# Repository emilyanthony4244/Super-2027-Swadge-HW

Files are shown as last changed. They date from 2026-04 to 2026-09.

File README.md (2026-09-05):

# Super Magfest 2027 Swadge Hardware

## Welcome

This is the hardware repository for the Super Magfest 2027 Swadge.

The corresponding firmware repository for the Super Magfest 2027 Swadge [can be found here](https://github.com/AEFeinstein/Super-2024-Swadge-FW).

If you have any questions, feel free to create a Github ticket or email us at circuitboards@magfest.org.

## Render

Coming eventually!

## Schematic

Coming eventually!

## Directories

### `art`

This directory has the SVGs used to generate the KiCad files. The SVGs are drawn in [Inkscape](https://inkscape.org/).

### `docs`

This directory has documentation on the hardware. [Start Here](/docs/structure.md)  

### `Swadge-Parts`

This directory is a git submodule which has all the parts, footprints, and 3D models used in the KiCad project.

### `Swadge-HW`

This directory has the KiCad project for the main Swadge PCB.

### `Swadge-HW/3d Print`

This directory has the 3D print files for the 2027 Swadge.

### `Swadge-HW/Manufacturing Information`

This directory has information about manufacturing the Swdage PCB.

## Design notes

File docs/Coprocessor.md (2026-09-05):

# CH32 Coprocessor
The Swadge has a CH32V003F4U6 as a coprocessor

## Pin Assignment

| PIN | FUNCTION | NOTE |
| --- | --- | --- |
| 1 | BTN_1 | Can be made reset pin |
| 2 | TOUCH_A | --- |
| 3 | TOUCH_G | --- |
| 4 | GND | --- |
| 5 | BTN_5 "Right" | --- |
| 6 | 3V3 | --- |
| 7 | BTN_2 "Left" | --- |
| 8 | Unused | --- |
| 9 | BTN_4 "Down" | --- |
| 10 | Unused | --- |
| 11 | VMON | ADC |
| 12 | CHARGE | --- |
| 13 | STANDBY | --- |
| 14 | BTN_6 "MENU" | --- |
| 15 | CH32_COMMS | --- |
| 16 | BTN_3 "PAUSE" | --- |
| 17 | BTN_8 "B" | --- |
| 18 | BTN_7 "A" | --- |
| 19 | TOUCH_21 | --- |
| 20 | TOUCH_M | --- |

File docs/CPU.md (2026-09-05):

# Background
The Swadge is powered by an ESP32 module with integrated bluetooth antenna

# Pin Assignment ESP32-S3-WROOM-1-N16R8

## Fixed Assignment

The following IO is fixed by hardware constraints and cannot be reassigned

1 - Ground  
2 - 3V3 
3 - Chip Enable 
13 - USB(-)  
14 - USB(+)  
27 - Boot Pin
28 - Not Connected, Reserved for PSRAM  
29 - Not Connected, Reserved for PSRAM 
30 - Not Connected, Reserved for PSRAM 
37 - TXD0  
36 - RXD0  

## Pin Table

| Pin Number | IO | Use | Alternate Features | Notes |
| --- | --- | --- | --- | --- |
| 1 | Ground | Ground | N/A | --- |
| 2 | 3V3 | 3V3 | N/A | --- |
| 3 | EN | EN | N/A | --- |
| 4 | GPIO4 | TOUCH4 | ADC1_CH3 | --- |
| 5 | GPIO5 | TOUCH5 | ADC1_CH4 | --- |
| 6 | GPIO6 | TOUCH6 | ADC1_CH5 | --- |
| 7 | GPIO7 | TOUCH7 | ADC1_CH6 | --- |
| 8 | GPIO15 | SAO_A | XTAL_32K_P, ADC2_CH4 | --- |
| 9 | GPIO16 | SAO_B | XTAL_32K_N, ADC2_CH5 | --- |
| 10 | GPIO17 | MIC via ADC2_CH6 | ADC2_CH6 | --- |
| 11 | GPIO18 | TFT_RESET | ADC2_CH7 | --- |
| 12 | GPIO8 | TOUCH8 | ADC1_CH7| --- |
| 13 | GPIO19 | USB (-) | GPIO19, ADC2_CH8 | --- |
| 14 | GPIO20 | USB (+) | GPIO20, ADC2_CH9 | --- |
| 15 | GPIO3 | TOUCH3 | ADC1_CH2 | --- |
| 16 | GPIO46 | Unused  | --- | Strapping Pin |
| 17 | GPIO9 | TOUCH9 | GPIO9, ADC1_CH8 | --- |
| 18 | GPIO10 | FSPI_CS0 (LCD) | GPIO10, TOUCH10, & ADC1_CH9 | --- |
| 19 | GPIO11 | FSPID - TFT_SDA | GPIO11, TOUCH11, & ADC2_CH0 | --- |
| 20 | GPIO12 | FSPICLK - TFT_CLK | GPIO12, TOUCH12, ADC2_CH1 | --- |
| 21 | GPIO13 | TFTATP | GPIO13, TOUCH13, ADC2_CH2 | --- |
| 22 | GPIO14 | TOUCH14 | GPIO14, ADC2_CH3 | --- |
| 23 | GPIO21 | SLEEP | GPIO21 | --- |
| 24 | GPIO47 | SPK | GPIO47 | --- |
| 25 | GPIO48 | SPK_SHDN | GPIO48 | --- |
| 26 | GPIO45 | Unused | GPIO45 | N/A | Strapping Pin |
| 27 | GPIO0 | Boot / "Button UP"| GPIO0 | Strapping Pin for Boot Source |
| 28 | GPIO35 | Not Connected | GPIO35 | Reserved for Octal SPI PSRAM |
| 29 | GPIO36 | Not Connected | GPIO36 | Reserved for Octal SPI PSRAM |
| 30 | GPIO37 | Not Connected | GPIO37 | Reserved for Octal SPI PSRAM |
| 31 | GPIO38 | TFT_RS | GPIO38 | --- |
| 32 | GPIO39 | CH32_COMMS | GPIO39 | --- |
| 33 | GPIO40 | I2C_SDA  | GPIO40 | --- |
| 34 | GPIO41 | I2C_SCL  | GPIO41 | --- |
| 35 | GPIO42 | LED | GPIO42 | --- |
| 36 | RXD0 | RXD0 | GPIO44 | --- |
| 37 | TXD0 | TXD0 | GPIO43 | --- |
| 38 | GPIO2 | TOUCH2 | GPIO2 & ADC1_CH1 | --- |
| 39 | GPIO1 | TOUCH1 | GPIO1 & ADC1, CH2 | --- |
| 40 | GND | GND | --- | --- |
| 41 | GND | GND | --- | --- |

# Basic Operation

## BOOT
When the ESP32 Module first receives power, it enters its Chip Reset State. The Chip Reset State can also be induced by using a physical tool to short EN (PIN 3) to ground. The recommended way of doing this is by shorting C13 with a screwdriver if removal of the battery is not desired.

In the Reset State the status of the four strapping pins combined with the e-fuses determine the boot configuration.

Chip Boot Mode is determined by GPIO0 and GPIO46.
GPIO0 has a default weak internal pull up as well as a 10k external pull up via R12. GPIO0 can be pulled low by holding the "UP" button during the boot initialization. 
GPIO46 has a default weak internal pull down, and is otherwise unused on the Swadge. It should always be held low on Reset.

When GPIO0 is High, its default state, the ESP32 boots from its SPI flash memory.
When GPIO0 is Low, it enters download boot mode. In this mode the ESP32 will boot via USB, Serial, or JTAG.

## SLEEP
When Pin 23 is pulled low by the power switch the ESP32 is pulled into ULP deep sleep.
The Power Management Unit is operating any time the chip has power.
The ESP32 has four predefined power modes: Active, Modem Sleep, Light Sleep, and Deep Sleep

### Deep-Sleep
When in deep sleep the system is running on its internal RC_SLOW_CLK. Only select RTC ULP peripherals are available.

### Light-Sleep
When in light sleep the high speed clock and CPUs are not running, but the digital system retains the memory state to resume operation.

### Modem-Sleep
When in modem sleep everything is operating except the analog RF radio circuits.

## Watchdogs
There are four watchdog times:
Super Watchdog (SWD), RTC Watchdog (RWDT), and Two Main System Watchdogs (MWDT0 & MWDT1)

### Analog Super Watchdog
The SWD is a base analog timer that must be reset every second by the ULP coprocessor or the ESP32 will enter the [Reset State](#boot). The SWD has an interrupt register that will indicate a request aproximately 100ms before the SWD expires.

### Digital Watchdog
RWDT, MWDT0, and MWDT1 are 32 bit counters which have four programable trigger points. Each trigger point can select from the following actions: Disabled, Interrupt, CPU Reset (Of a single processor), and Core reset. RWDT additionally has access to the action of [System Reset](#boot). By default, stage 0 for RWDT is set to system reset during the initial boot process, to allow for automatic recovery.

# Ultra Low Power Coprocessor

# RISC Processor Cores

# PERIPHERALS

## UART

## I2C

## SPI

## LED PWM

## Touch Sensing

## ADC

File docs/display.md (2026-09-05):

# TFT Display

The Swadge has a RB017A1505A Display

Backlight is controlled via PWM though signal TFTATP

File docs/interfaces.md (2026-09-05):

# Swadge Interfaces

The Swadge has the following interfaces:
USB 2.0 via J1, between the [CPU](/docs/CPU.md) and the USB port  
UART programming
SAO port, including two GPIO and I2C  
Audio Aux Port  

## USB

The USB 2.0 signal from the port to the CPU
Have an approximately 90 ohm differential impedance. It is recommended to achieve this with a tightly coupled routing and coplanar ground.
> Recommended 9.5 mil trace width with 5 mil spacing when coplanar ground is used.
The USB port to ESP32 trace length should be less than 2 inches
trace length must be less than 6 inches.
The USB lines should have termination resistors at the USB Jack.
The USB lines should have a total skew offset of less than 50ps

## I2C

The I2C_SDA and I2C_SCL lines should be routed with a total skew offset between them of no more than 200ps
It is recommended to have termination resistors at the furthest end of the I2C lines from the ESP32
It is recommended to run I2C lines through pads rather than stub them off to minimize all stub lengths. The SAO will by necessity be the longest stub.

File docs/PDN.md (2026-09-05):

# Background
The Power Distribution Network is the subsystem responsible for generating all applicable global voltage rails from the available power sources.
The global power rails are “GND” and “3V3”
The available power sources are “5VIN” and “V_BATT”
Local power rails are “2V8_LCD”, “TFT_LED”

| Net | Description | Interface |
| --- | --- | --- |
| GND | Global Ground Net, common return path for all portions of the swadge with the exception of the isolated BATT_N | Global |
| 3V3 | Global 3.3V DC power supply | Global |
| 5VIN | USB Supplied 5V DC, Used to either power the swadge or to recharge the onboard battery | J1 |
| BATT_P | Battery Positive Voltage | --- |
| BATT_N | Battery Negative Voltage, U4 Isolates the battery return from global ground when 
| LCD28 | 2.8V Display Logic Power | --- |
| TFT_LEDA | PWM Display Backlight Power | --- |

# Requirements
The PDN shall accept a nominal 5V DC from USB input J1
The PDN shall provide power from the USB source when 5VIN is in the range of 4.35VDC to 5.5VDC.
The PDN shall accept a range of voltage from the battery(s) between 2.4V and 5.5V.
The PDN shall generate a regulated 3.3V DC from a range of input voltages for both battery and USB operation
The PDN should minimize both conducted and radiated EMI and its effects on other subsystems of a Swadge and external items.

# Implementation
## Auctioneering
The [3.3V Regulator] (#3V3) is fed from an auctioneered supply via Q2. Q2 and D22 passively switch the source to the system to whichever has the higher voltage. The total system current passes through fuse F1.

## 3V3  
The 3.3Vdc power is regulated by an aerosemi MT3410 synchronous switching regulator. The MT3410 is a SOT23-5 Package integrated switch and controller. The Feedback reference is 0.6V. The regulator is rated to operate from 2.3 up to 6V input voltage. The control has a 1.9V undervoltage lockout. As Vin drops to the regulator setpoint the control shifts from switching buck to LDO mode. The switching frequency is nominally 1.2MHz.  
A 2.2uF switching inductor is used. The FB network is set up with a 10k and a 43k, for a 10/53 reduction on the Vout to produce a nominal 3.18V output before accounting for component error. The component datasheet recommends a 10uF ceramic capacitor on both the input and output. In the Swadge Prototype a 1uF input capacitor was used and a 1uF paired with a 22uF output capacitor was used.

## Charging
USB Power is provided to the charging circuit in parallel to the system. A TP4056 BMS regulates VBATT to maintain a correct charge profile. an NTC thermistor is used to provide temperature feedback and limit charging in abnormal temperature conditions. The Charging circuit provides two status LEDs for Charging and Standby, as well as digital inputs to the CH32 coproessor. When the USB port is not providing power, the charging system is not active.

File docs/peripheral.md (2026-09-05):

# Summary

The Swadge has many peripherals to enhance user exierpience

## Lighting

The Swadge lighting is performed with SK6812 side firing individually addressable RGB LEDs.  
Each LED acts as a serial shift register with 24bits of RGB data. They are daisy chained together.

## Inertial Measurement Unit

The Swadge has an IMU to detect motion of the device. The IMU reports its measurements over the I2C bus. The IMU has a fixed I2C address of 0x6A

## SAO

There is an Swadge Add-On connector

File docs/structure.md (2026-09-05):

The hardware layout is composed of the following subsections:  
[Primary CPU](/docs/CPU.md)  
[Power Regulation and Distribution Network](/docs/PDN.md)  
[Coprocessor](/docs/Coprocessor.md)  
[User Inputs](/docs/userIO.md)  
[Graphical Display](/docs/display.md)    
[Audio Input/Output](/docs/audio.md)    
[Peripherals](/docs/peripheral.md)  

The Swadge provides the following external interfaces:
USB-C
Programming UART
SAO
Auxiliary Audio Jack\
Wifi
Bluetooth

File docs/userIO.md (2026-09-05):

# The user IO is as follows:  

## Buttons
8 Buttons

| NET | FUNCTION | NOTE |
| --- | --- | --- |
| BTN_1 | UP | Also the Boot |
| BTN_2 | LEFT | --- |
| BTN_3 | PAUSE | --- |
| BTN_4 | DOWN | --- |
| BTN_5 | RIGHT | --- |
| BTN_6 | MENU | --- |
| BTN_7 | A | --- |
| BTN_8 | B | --- |

## Touch
2 Touch Strips, 5 zones each
4 Touch Button Zones

| NET | FUNCTION | IO |
| --- | --- | --- |
| TOUCH_1 | ZONE L1, Top Left | ESP32 |
| TOUCH_2 | ZONE L2, Left | ESP32 |
| TOUCH_9 | ZONE L3, Middle Left | ESP32 |
| TOUCH_14 | ZONE L4, Left | ESP32 |
| TOUCH_3 | ZONE L5, Bottom Left | ESP32 |
| TOUCH_8 | ZONE R1, Top Right | ESP32 |
| TOUCH_4 | ZONE R2, Right | ESP32 |
| TOUCH_5 | ZONE R3, Middle Right | ESP32 |
| TOUCH_6 | ZONE R4, Right | ESP32 |
| TOUCH_7 | ZONE R5, Bottom Right | ESP32 |
| --- | --- | --- |
| TOUCH_21 | Touch Button | --- |
| TOUCH_M | Trihard Top Button | --- |
| TOUCH_A | Trihard Left Button | --- |
| TOUCH_G | Trihard Right Button | --- |

## Analog
1 volume adjust knob

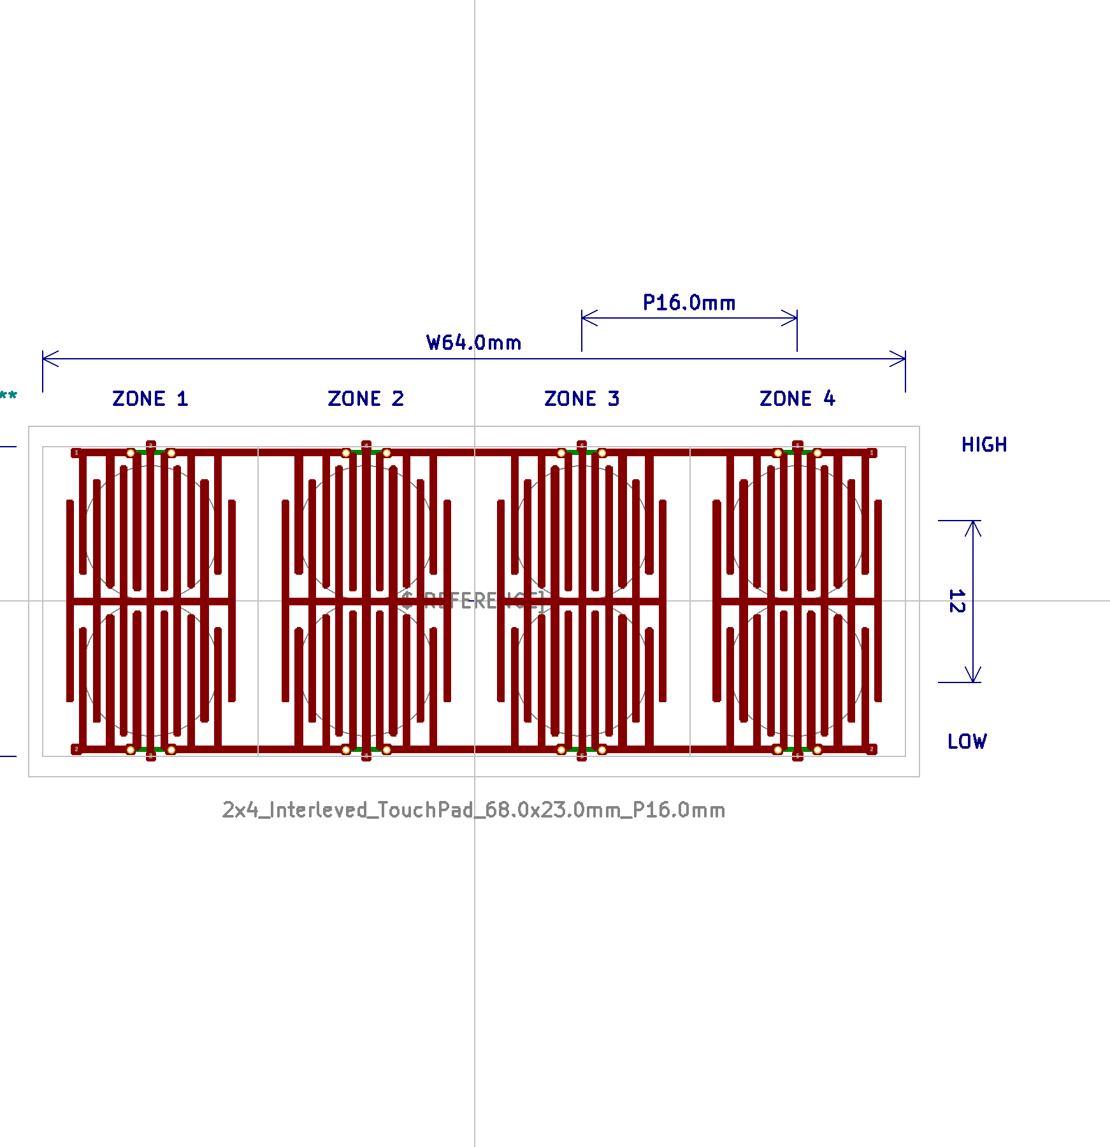
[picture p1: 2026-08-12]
Swadge-HW/.local/2x4_Interleved_TouchPad_68.0x23.0mm_P16.0mm.png

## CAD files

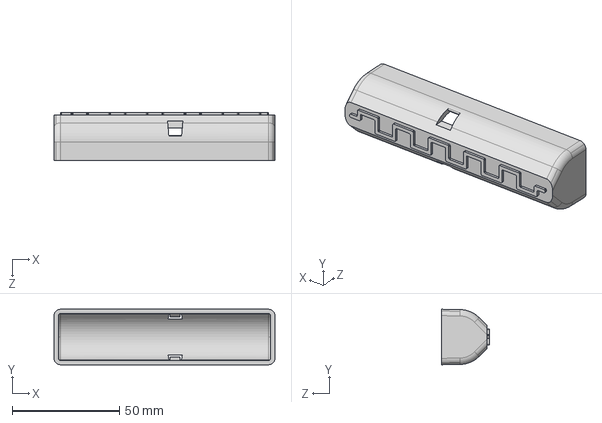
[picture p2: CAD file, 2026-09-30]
3D-Print/Rev1 Battery Cover - IM.STEP
103.1 x 25.9 x 22.2 mm

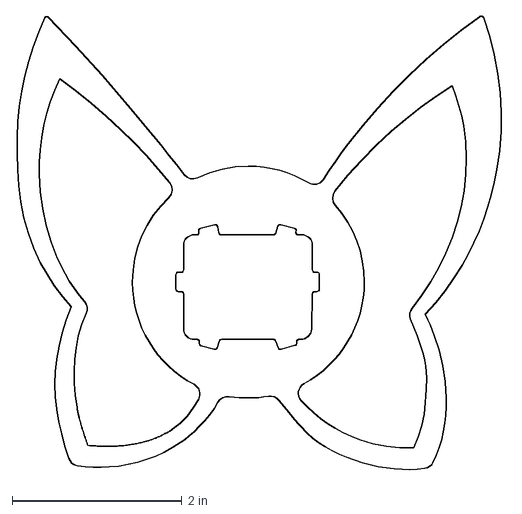
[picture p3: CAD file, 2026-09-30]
art/acylic_9212026.dxf
5.77 x 5.39 in

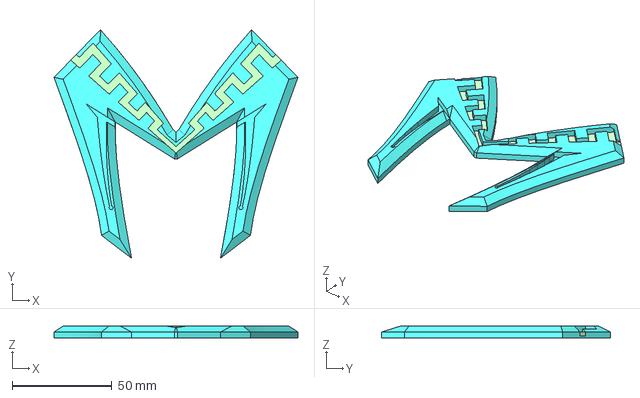
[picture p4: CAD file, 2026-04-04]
Swadge-HW/3D-Print/M-Diffuser.step
122.3 x 114.6 x 6.00 mm

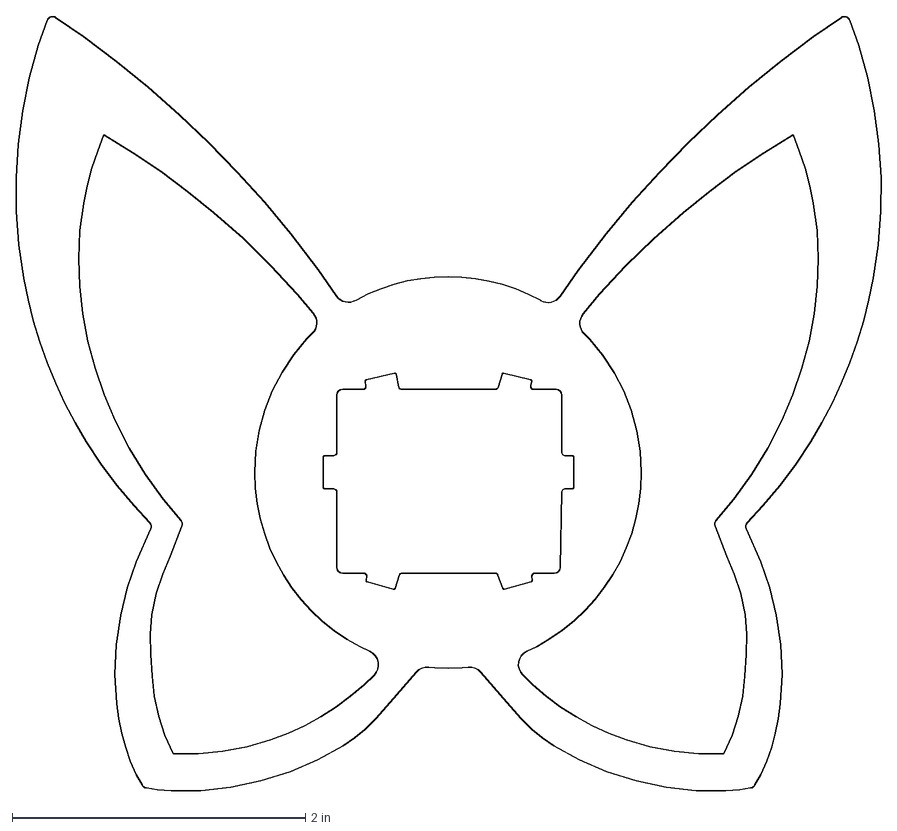
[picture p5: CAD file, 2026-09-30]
art/acylic_9292026.dxf
5.90 x 5.28 in

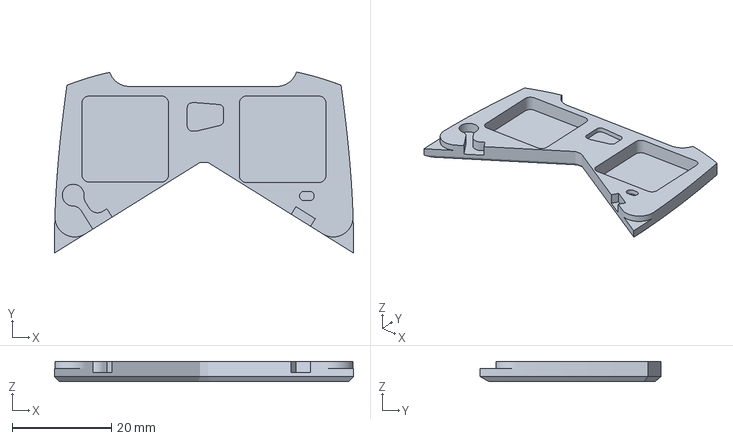
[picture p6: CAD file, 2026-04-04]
Swadge-HW/3D-Print/Open-Visor-orca.3mf
60.3 x 36.5 x 4.05 mm

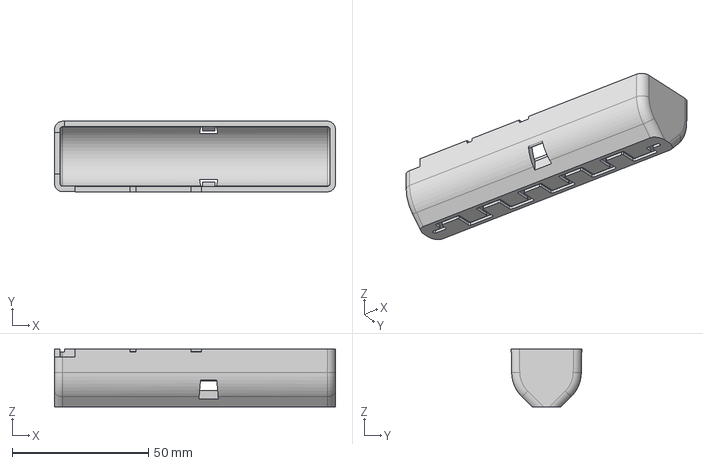
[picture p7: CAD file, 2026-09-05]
3D-Print/Rev0 Battery Cover - 3D Print.step
103.1 x 25.9 x 21.2 mm

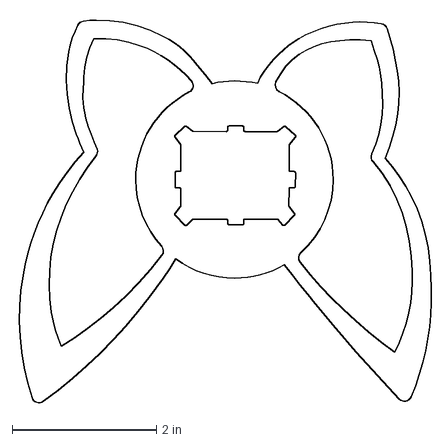
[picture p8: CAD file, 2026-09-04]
art/acrylic.dxf
5.76 x 5.36 in

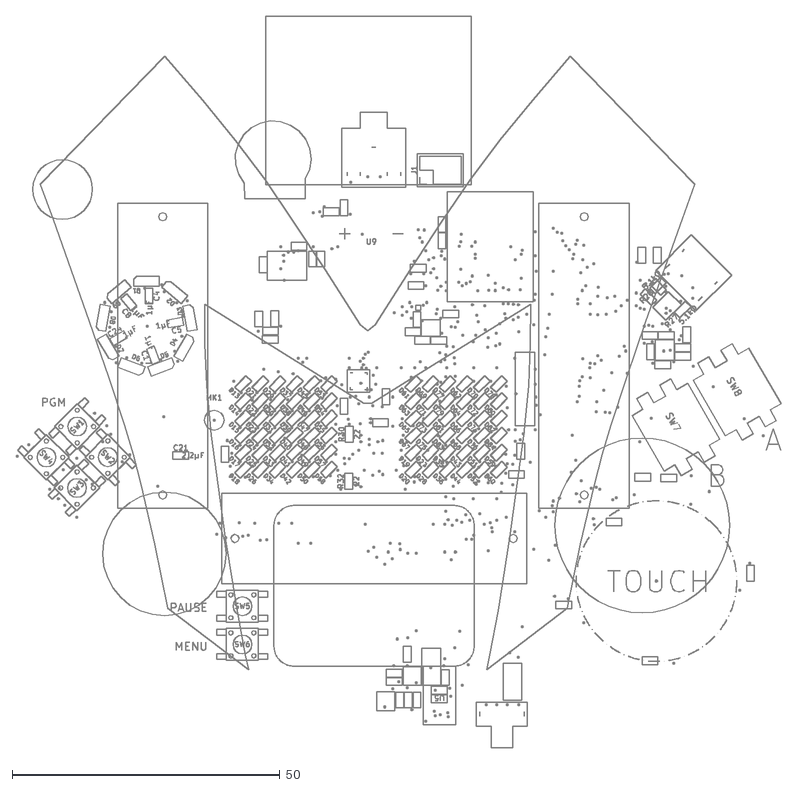
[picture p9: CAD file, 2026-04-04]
art/acrylic_7162025.dxf
142.9 x 136.6

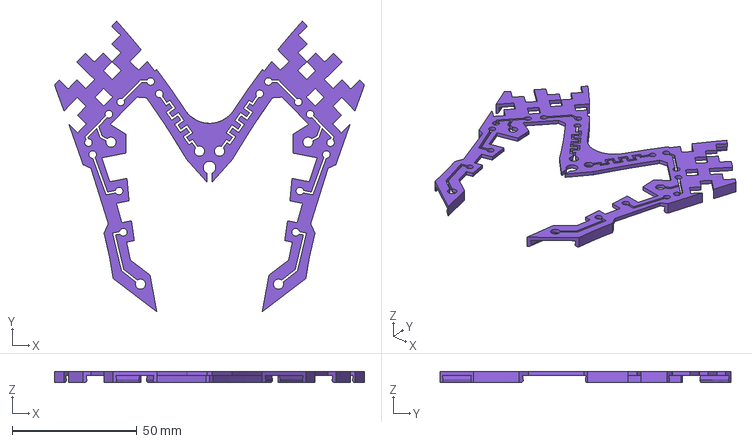
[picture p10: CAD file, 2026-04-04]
Swadge-HW/3D-Print/Corruption Crest.step
124.0 x 116.3 x 4.60 mm

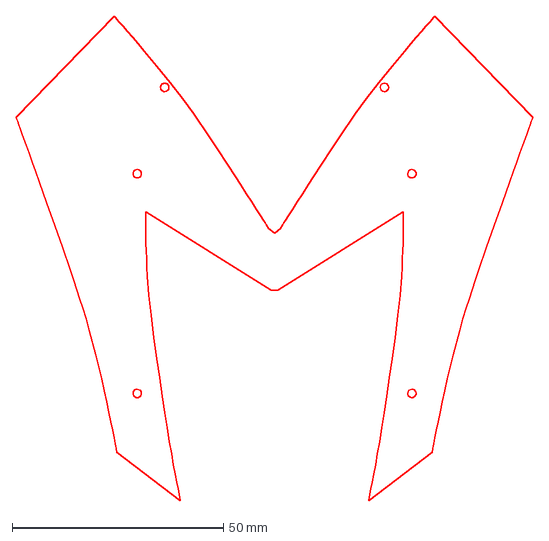
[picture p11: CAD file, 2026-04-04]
art/acrylic_992025.dxf
122.3 x 114.6 mm

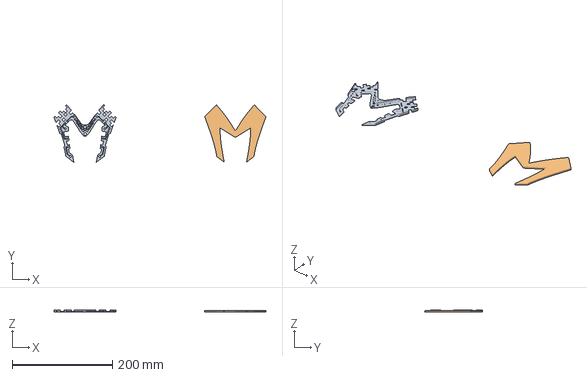
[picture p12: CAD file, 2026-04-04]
Swadge-HW/3D-Print/Corruption-Crest+Acrylic-Orca.3mf
423.2 x 115.4 x 4.60 mm
Corruption-Crest
Faux-Acrylic

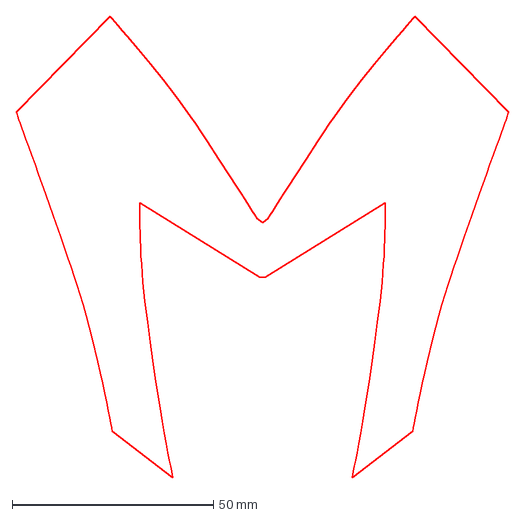
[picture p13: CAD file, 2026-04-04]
art/acylic_10102025.dxf
122.3 x 114.6 mm

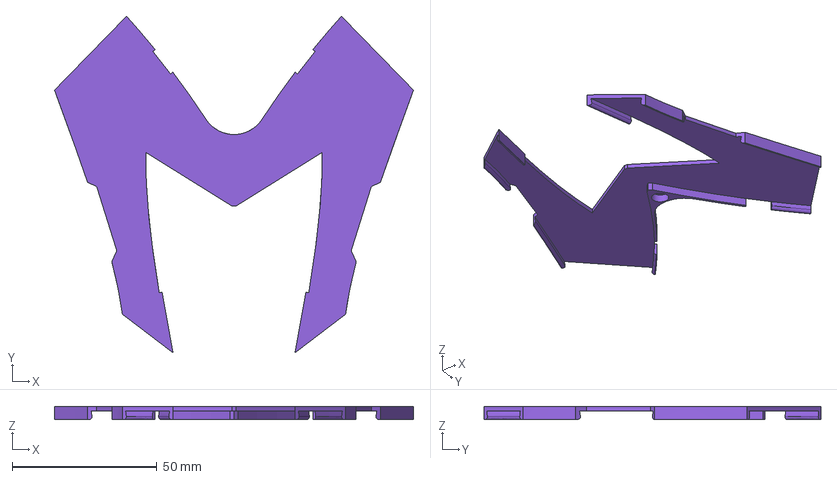
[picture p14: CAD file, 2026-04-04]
Swadge-HW/3D-Print/Crest-Diffuser-Template.step
124.0 x 116.3 x 4.60 mm

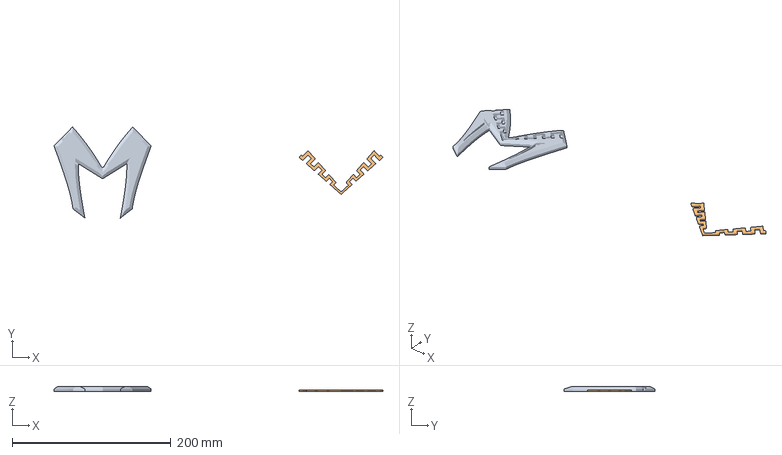
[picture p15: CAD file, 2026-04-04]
Swadge-HW/3D-Print/Fancy-M-Diffuser.3mf
413.9 x 114.6 x 6.00 mm
M-Diffuser.stl_1
M-Diffuser.stl_2

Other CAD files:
Swadge-HW/3D-Print/Pulse-Visor.step
Swadge-HW/3D-Print/Open-Visor-orca-MK4.3mf
Swadge-HW/3D-Print/Wub-Tank-Proto.step
3D-Print/Rev0 Battery Cover - IM.step
3D-Print/Rev0 Battery Cover - IM.SLDPRT

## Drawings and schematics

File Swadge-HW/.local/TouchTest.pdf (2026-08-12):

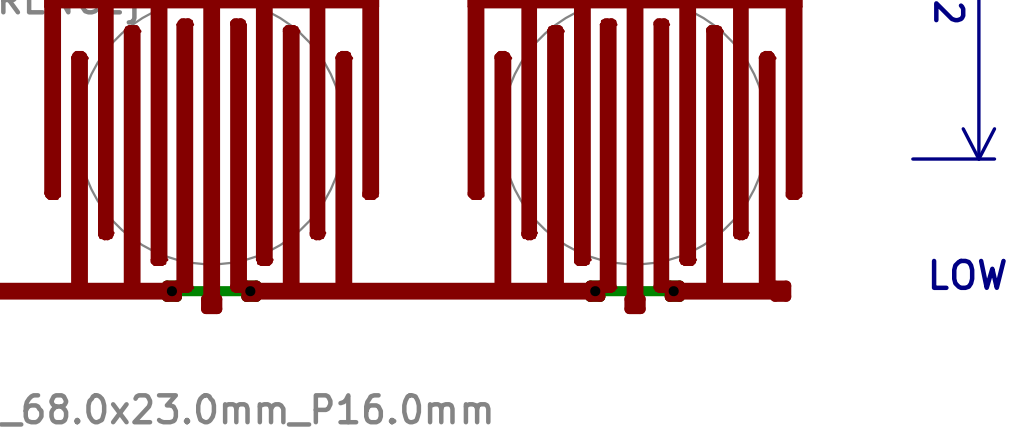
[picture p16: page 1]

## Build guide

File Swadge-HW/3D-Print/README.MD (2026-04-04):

# Super 2026 Swadge 3D Printing Assets

Introducing the WUB TANK, the newest addition to the Swadge shell collection

## Built With

* [Fusion 360]( https://www.autodesk.com/products/fusion-360/overview?term=1-YEAR&tab=subscription) 
* [Blender](https://www.blender.org) 
* [Orcaslicer](https://github.com/OrcaSlicer/OrcaSlicer?tab=readme-ov-file)

## Getting Started

The included files are STEP type so they can be modified to your liking, and most slicer programs will readily load them. The Wub-Tank-Proto.step is the final fit check model before art assets were added. Designed to be readily printable. Recommended settings: 0 top/bottom layers for exposed (honeycomb) infill effect when printed as is.

## Recommended Materials

PLA 
PETG
TPU

## Assembly

The WUB TANK Shell requires a single M3x8 screw.

## Secret 3D Upgrade Add-ons

In addition to the shell model, there are a number of 3D-printable accessories for the Swadge this year. There are STEP files for each, and customized Orcaslicer 3MF project files are also included as reference, or ready to print for the Prusa Core ONE. 

- Pulse-Visor: SPECIFIC FILAMENT REQUIRED. The Pulse Visor was designed to be printed with Cookiecad "Black Star Stuff PLA". Clear PLA or PETG should work as well. As long as the filament isn't to opaque, the lens region of the visor should be thin enough to see the LED's but they may be obscured. Install using thin double-sided tape. Try printing this with a holographic print bed. Enjoy!

- Corruption Crest: A friction fit add-on that attaches to the standard acrylic diffuser. It was designed to be one of several Megaman style powerups. I recommend printing this in purple filament.

- Crest Diffuser Template: A version of the corruption crest with all original art removed so you can design your own. GO NUTS! Just don't cut away the tabs that hold it on.

- M-Diffuser: WARNING ADVANCED!!! Designed as a substitute for the included acrylic diffuser, since the prototype did not include one. If you want to make one, you'll need some clear/translucent filament, double sided tape, and be gentle when removing the acrylic so as not to damage the PCB surface. For best results use a clear filament and 100% concentric infill for the bottom 3mm, and a translucent color for the remainder with the top layers turned off to expose the infill with your choice of infill pattern. Print the squarewave insert seperately (in neon green or glow in the dark filament). Optional... change filament partway through to make it extra fancy.

## Contributing

Contributions are what make the open-source community such an amazing place to learn, inspire, and create. Any contributions you make are greatly appreciated!

If you have a suggestion that would make this better, please fork the repo and create a pull request. You can also simply open an issue with the tag "enhancement".
Don't forget to give the project a star! Thanks again!

1. Fork the Project
2. Create your Feature Branch (`git checkout -b feature/AmazingFeature`)
3. Commit your Changes (`git commit -m 'Add some AmazingFeature'`)
4. Push to the Branch (`git push origin feature/AmazingFeature`)
5. Open a Pull Request

## License

[MIT License](https://github.com/AEFeinstein/Super-2026-Swadge-HW/blob/main/LICENSE)

## Contact

* Emily Anthony - [@thelegendofemily](https://www.thelegendofemily.com) 
* Greg Lord - [@gplord](https://www.gplord.com/)
* Erik Jacobs - [@Eriktronic3D]

## Acknowledgments

* The Swadge team for idea generation, continuous feedback, and excellent vibes
* MAGFest volunteers and employees for their overwhelming support and willingness to help push this side project

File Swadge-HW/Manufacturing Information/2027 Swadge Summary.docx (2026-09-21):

Summary of Request:

Qty 2500 pcs assembled, flashed and tested with acrylic piece, two identical PCBs except solder mask color, specified below.

Please quote HASL Lead Free finish.

Please use existing inventory from the 2025 swadge order first from the 015-Magfest warehouse and deduct the cost of materials accordingly.

PCB Properties:

1. Two layer board
2. Two-side assembly
3. 1.6mm FR4
4. Qty 1800 COLOR solder mask
5. Qty 700 COLOR solder mask
6. White silkscreen on both
7. V-groove where possible, avoid sharp edges wherever possible. We want to approve tooling locations
8. 1oz Copper
9. Silkscreen should be sharp, not splotchy

Acrylic Properties:

1. One piece of acrylic per-PCB, mockup image is shown below in Assembly section
2. Matte Transparent (P422)
  a. “Winter Melon White”
  b. Edge should be matte, not clear
3. 3mm thick
4. No engraving

Assembly Information:

18650 holder

Please be aware the part should mount flush to the PCB. If installed backwards, it will stick up on one corner.

TODO ADD IMAGES

The battery cover is designed to be clipped and retained on BT1. Please secure with a little bit of silicone or flexible glue on the BT1 component if there is a concern.

TODO ADD IMAGES

There are 4 THT parts. These parts shall have their leads clipped close to PCB. See notes below.

Through hole leads shall not be sharp.

1. 1x Headphone Jack -> J2
  a. The jack has a lip that should overhang the pcb. Example of one that doesn’t is shown below. This should overhang correctly and sit flush.

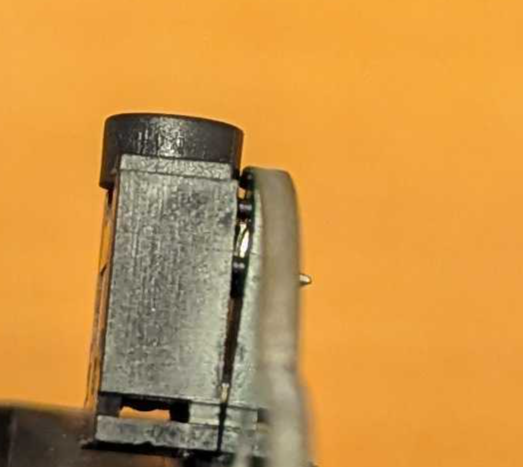
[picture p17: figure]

2. 1x Switch -> SW1
  a. No specific notes for this component
3. 1x 3x2 Pin Socket -> J1
  a. No specific notes for this component
4. 1x Volume control knob -> RV1
  a. No specific notes for this component

Screen Assembly:

LCD ribbon shall first be looped through the notch provided in the PCB. Please review photos:

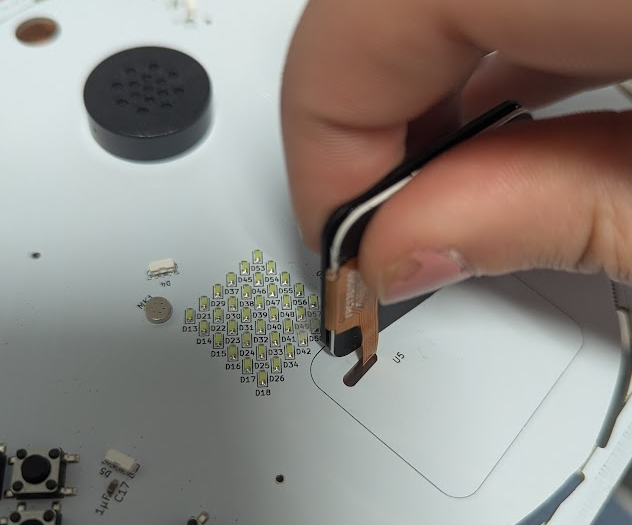
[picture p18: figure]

FPC cable connection is on the back of the board.

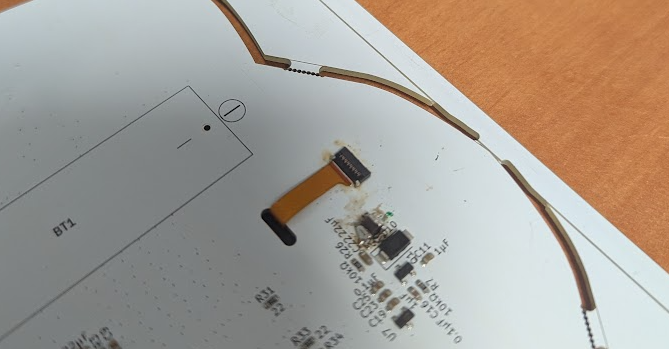
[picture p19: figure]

The ribbon cable shall have no twists to be installed – it is simply a fold through the hole to the other side of the board.

LCD shall be taped down after plugging in using double sided tape to PCB. Please use clear, thin, double-sided tape like this 0.1mm PET:

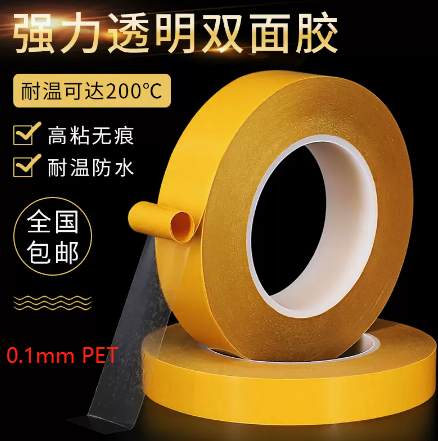
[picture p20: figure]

LCD should land approximately within the silkscreen bounds drawn and be straight.

Acrylic Assembly:

Acrylic must have protective paper peeled off and taped to PCB using the same double-sided tape as the display. Acrylic will be approximately flush with the board edges.

Image of Acrylic, highlighted in green. LEDs are adjacent to the acrylic in the circled locations:

TODO

It is recommended to apply two pieces of tape in the following general locations underneath the acrylic, shown as rectangles in red. Do not use glue.

Tape dimensions for the acrylic shall be as follows:

- No greater than 7mm in width
- 45mm in length

Programming:

1. A Python programming script will be provided.
2. The boards connect with USB-C and do not require external programming hardware
3. The programming script can program many units in parallel
4. Each unit is programmed in ~15 seconds

Instructions will be provided.

Testing:

1. Each unit will be tested after programming.
2. Testing involves pressing all buttons and validating the display and LEDs.
3. We also have an IMU calibration step which requires the device be held on its face, then its back for 5 seconds each. Then held upright, and upside down for 5 seconds each.

Detailed instructions and video will be provided.

Schedule:

Expected Supplier deliveries:

September 25 2026: Ronbo Electronics ship 2,500 of RB017A1505A-CG01A LCD to Elecrow

Antenk Electronics inc ship 2500 of BBC-M-GO-A-18650-042 to Elecrow

Manufacturing Timeline:

Week 0:

September 14, 2026: RFQ Submitted by MAGFest to Elecrow

September 18, 2026: Quote completed and returned to MAGFest.

Upon Receipt of quote or prior: MAGFest will submit final documents to Elecrow

MAGFest will pay Elecrow for samples and full order.

Elecrow will purchase components for a full 2500 order.

MAGFest will provide basic test firmware for boards.

Week 4:

October 18, 2026: Elecrow will send MAGFest QTY 10 PCBs as samples, via DHL ASAP.

Please do not use re-shipper.

To avoid delays, any components that could not be sourced in time may be unpopulated, we have spares in the USA. Please check with us first.

Please ship with requested 18650 batteries packed separately. Do not wait for injection molded pieces to be delivered.

Week 7:

November 6, 2026: MAGFest will provide feedback needed and will approve the final order of 2500.

Week 11:

November 11, 2026: MAGFest will provide FINAL firmware to be flashed to all units OR direct Elecrow to flash test firmware only at or before this date.

Week 14:

December 18, 2026: Elecrow will ship MAGFest full 2500 order via DHL ASAP.

Please do not use reshipper.

Please ship with requested 18650 batteries installed.

Expect delivery in Maryland, USA on or prior to December 25 2026.

Changelog:

Subject: PCB Hardware RFQ for Magfest 2027 Swadge September 15 2026 To: Roy@elecrow.com

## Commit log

2026-04-04 reset to 2027
    delete board, adjust schematic
    [Swadge-HW.kicad_pcb, Swadge-HW.kicad_sch]
2026-04-07 Create ESP32_S3_IO.xlsx
    Add a Cross Reference Table for every possible ESP32 IO mapping.
    [ESP32_S3_IO.xlsx]
2026-07-11 Prototype Setup
    Initial Commit in Prototype Branch
    Made 2027 Swadge Hierachical
    Added Optional FSPI Expansion, currently populated with a 32MB Flash
    TBD on Audio
    No Battery In Schematic Yet
    [Swadge-2027-3V3.kicad_sch, Swadge-2027-ACC.kicad_sch, Swadge-2027-BMS.kicad_sch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]
2026-07-12 Bus Renames
    Since we really don't have that many signals I just ditched the bus prefixes and Alias'd them directly.
    Added a bus for the interupt and status signals even if they are never used.
    [Swadge-2027-ACC.kicad_sch, Swadge-2027-CPU.kicad_sch, Swadge-2027-Coprocessor.kicad_sch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]
2026-07-12 Add External RTC
    Added External RTC to Swadge 2027
    [Swadge-2027-CPU.kicad_sch, Swadge-2027-RTC.kicad_sch, Swadge-HW.kicad_sch]
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2026-07-12 Cleanup
    Renamed some components
    Added in some net directives
    [Swadge-2027-CPU.kicad_sch, Swadge-2027-PDN.kicad_sch, Swadge-2027-RTC.kicad_sch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]
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2026-07-19 major routing changes
    Routed SPI
    Started Test Routing Touch Inputs
    Rough routing for LCD Power
    [Swadge-2027-3V3.kicad_sch, Swadge-2027-ACC.kicad_sch, Swadge-2027-BMS.kicad_sch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]
2026-07-20 Layout Changes
    Moved USB 10deg around perimeter to get it closer to the ESP32 and the left thigh.
    Substantially compressed BMS and 3.3V layout
    Started Routing the Touch Inputs
    [Swadge-2027-BMS.kicad_sch, Swadge-2027-PDN.kicad_sch, Swadge-HW.kicad_pcb]
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2026-07-21 Reassigned CH32 IO and Initial Button Routing
    Rough in Button Routing
    Reassigned CH32 IO mapping to better reflect button locations.
    Temporarily added the unused interrupts to the CH32 because why not.
    [Swadge-2027-CPU.kicad_sch, Swadge-2027-Coprocessor.kicad_sch, Swadge-HW.kicad_pcb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]
2026-07-28 Change to ESP32-S3-MINI-1
    Change U1 to ESP32-S3-MINI-1-N4R2
    Update IO Mapping
    [Swadge-2027-CPU.kicad_sch, Swadge-2027-Coprocessor.kicad_sch, Swadge-2027-Exp.kicad_sch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]
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2026-07-28 Update Library Links
    Point to Swadge Parts link
    [Swadge-2027-BMS.kicad_sch, Swadge-2027-CPU.kicad_sch, Swadge-2027-PDN.kicad_sch]
2026-07-30 Restart Routing From Scratch
    Total Restart of rough Routing with S3
    [Swadge-2027-CPU.kicad_sch, Swadge-2027-LCD.kicad_sch, Swadge-HW.kicad_pcb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]
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2026-07-30 Swapped Speaker Output and Mic input
    [Swadge-2027-CPU.kicad_sch, Swadge-HW.kicad_pcb]
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2026-08-06 fixing swadge-parts submodule
    I RTFM and have relinked it properly
    [BAT-TH_BH-18650-A1AJ005.step, BUZ-SMD_5P-L15.0-W15.0-P13.7-BL.step, CONN-TH_HR-PH2.0-WI-2P.step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]
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2026-08-20 Fixed 3D
    [Swadge-HW.kicad_pcb, Swadge-HW.kicad_sch]
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2026-08-27 Large Refactor
    Updated Symbols
    Removed Standby Signal to CH32 And replaced with more LEDs
    Added Local Net Names Where Applicable
    Renumbered Component by Region
    Moved VMON to downstream of Battery Disconnector to avoid continuous Drain
    Added Wing LEDs
    Added Decoupling Caps to CH32
    Added Extra Power Decoupling to Amp
    [Swadge-HW.kicad_sch]
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2026-08-28 Fixed text box on schematic
    [Swadge-HW.kicad_sch]
2026-08-28 Fix a misplaced junction on TP4056
    [Swadge-HW.kicad_sch]
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2026-08-30 Recenter LEDs
    Realign Screen and RGB LEDs
    Place Twinkle Lights Symmetric On Wings
    Awaiting Outline Updates
    [Swadge-HW.kicad_pcb]
2026-08-30 Linear LED Placement
    Todo adjust to be more organic with final outline
    [Swadge-HW.kicad_pcb]
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2026-08-31 Cleanup, fix battery, start routing
    [Swadge-HW.kicad_pcb, Swadge-HW.kicad_sch]
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2026-08-31 Schematic and BOM cleanup
    Check schematic, add notes in various places, clean up LCSC part numbers
    [Swadge-HW.kicad_sch]
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2026-08-31 Swap Right TouchPad Channels
    Better Routing
    [Swadge-HW.kicad_sch]
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2026-08-31 Fliped the LED 9 so it’s not in the acrylic
    [Swadge-HW.kicad_pcb]
2026-09-01 Switch to Centered Battery
    Incorporated Feedback from Dac
    Battery is now Centered
    Twinkle Lights have been deleted and replaced with 6 more RGB's.
    USB Moved to Account for Battery
    Outline needs to be updated
    [Swadge-HW.kicad_pcb, Swadge-HW.kicad_sch]
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2026-09-01 Add No-Connects On loose Pins
    [Swadge-HW.kicad_sch]
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2026-09-01 updated to new touchstrips
    Updated schematic and pcb with new touchstrips. will need to create a symbol at somepoint in the future for them
    [Swadge-HW.kicad_pcb, Swadge-HW.kicad_sch]
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2026-09-02 IO Route
    Todo: Reassign CH32 Pins
    Determine RGB LED interface with Acrylic
    Route Remaining LED signals once location is known
    Update Outline for externals/outer Acrylic edits
    Route Power
    [Swadge-HW.kicad_pcb, Swadge-HW.kicad_sch]
2026-09-02 Ground Plane Fixes at Touch Crossovers
    [Swadge-HW.kicad_pcb]
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2026-09-03 Update 18650 holder, fix more routing for big strips
    [Swadge-HW.kicad_pcb]
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2026-09-04 replace speaker, reroute
    [Swadge-HW.kicad_pcb, Swadge-HW.kicad_sch]
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2026-09-04 Schematic Tweak to fix Outline footprint assignement
    [Swadge-HW.kicad_sch]
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2026-09-05 Uncommit the Other Prototype Branch Info
    See Issue #11
    [Swadge-2027-3V3.kicad_sch, Swadge-2027-ACC.kicad_sch, Swadge-2027-BMS.kicad_sch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]
2026-09-05 Added Battery cover files
    - Created Battery cover
    - Added root level 3D-Print folder
    [Rev0 Battery Cover - 3D Print.step, Rev0 Battery Cover - IM.step]
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2026-09-06 Add missing No Connect
    [Swadge-HW.kicad_sch]
2026-09-07 Update Swadge-HW.kicad_pcb
    fix issues identified by jlc
    D13 wrong direction
    mic footprint error
    [Swadge-HW.kicad_pcb]
2026-09-08 order resubmit to JLC
    flipped D13
    re-placed some LEDs per Dac's request
    Adjusted mic footprint
    [Swadge-HW.kicad_pcb]
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2026-09-22 Add Reset
    Add Reset Switch
    Flip Touch 21 Back to Front Side
    Center SAO, Added "UP" marking
    Spin Trihad -30 degrees
    Pull Swadge-Parts Update
    [Swadge-HW.kicad_pcb, Swadge-HW.kicad_sch]
2026-09-22 Move DPAD and Touch Strip
    Move DPad to Top Left
    Move Touch Strip down
    Reposition Start and Pause
    Reposition Charging and Standby
    Rough Route What I can
    [Swadge-HW.kicad_pcb]
2026-09-22 More Moves
    Move Standby Light
    Add Tentative M3 Mounting Holes
    Probably convert those to NPTH M4's
    [Swadge-HW.kicad_pcb]
2026-09-22 Audio Rearangement
    Started Moving Audio Components
    Added Two More Potential Mounting Holes
    [Swadge-HW.kicad_pcb]
2026-09-23 Move Buttons and USB
    Moved D-Pad down 2mm
    Moved A&B down 4mm
    changed out PTH mounting holes for 3.2mm NPTH. Deleted two.
    [Swadge-HW.kicad_pcb]
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2026-09-25 Update Swadge-HW.kicad_pcb
    Footprint verified
    Checked it twice, then checked again
    Still bought wrong parts
    [Swadge-HW.kicad_pcb]
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2026-09-25 Remove Free CH32 Touch Pads From Schematic
    Dac Said now, everyone throw tomatoes at Dac.
    [Swadge-HW.kicad_sch]
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2026-09-25 Melt Traces
    Squiggles are pretty
    [Swadge-HW.kicad_pcb]
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2026-09-25 Add Placeholder Keepouts Under Touchstrips
    Need Better Dielectric, Fix keepouts along with footprints and art
    [Swadge-HW.kicad_pcb]
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2026-09-25 Fixed Some routing with Different nets touching
    - Fixed a couple instances of different routes touching.
    - Deleted some random tracks that there because of layout changes
    [Swadge-HW.kicad_pcb]
2026-09-26 Update Swadge-HW.kicad_pcb
    Routed RGB LEDs, adjusted RGB LED positions, updated REF DES for RGB LEDs.
    [Swadge-HW.kicad_pcb]
2026-09-26 Change Switch to 6mm Arm Version
    SW1 / Sleep Switch changed to 6mm lever arm
    [Swadge-HW.kicad_sch]
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2026-09-26 Updated Touchstrips to Library Versions
    Also Moved the strips 0.5mm inboard to better clear
    [Swadge-HW.kicad_pcb]
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2026-09-26 Pulled trace D12A a bit inward from the edge
    And moved D8A away from audio
    [Swadge-HW.kicad_pcb]
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2026-09-26 Tweak Amplifier Position
    Move amp a bit further away from touchstrip.
    Some more 3V3 and starting ground stitches
    [Swadge-HW.kicad_pcb]
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2026-09-26 DRC Fixes
    [Swadge-HW.kicad_pcb]
2026-09-26 Silk Screen Refdes cleanup
    Repositioning everything to not be over holes or each other
    [Swadge-HW.kicad_pcb]
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2026-09-26 DRC Closeout
    Final Issues:
    Mic Footprint
    BTN7/8 internal jumper for net connections
    Acrylic Footprint
    [Swadge-HW.kicad_pcb]
2026-09-26 Fix Lanyard Keepout
    And some other minor tweaks, rounded a few trace corners.
    [Swadge-HW.kicad_pcb]
2026-09-26 post review
    moved c71
    nudged a couple of components
    updated board silk
    adjusted mic footprint
    adjusted speaker footprint (+ location)
    added circuitboards and swadge info
    added logos to back
    ran drc, reviewed errors
    mild trace changes, pour cleanup, gnd stitching
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2026-11-10 LED routing
    Fix pad to trace on tweaked LED footprint
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
